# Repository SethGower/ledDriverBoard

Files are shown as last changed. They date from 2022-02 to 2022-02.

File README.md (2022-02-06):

# LED Driver Board

This is a Circuit and PCB design for an LED Strip driver I designed for personal use. I designed this to be able to have an LED strip on the perimeter of my bedroom. Given the perimeter is about 55 feet, this would require a lot of power. The original strip I looked at required 24W/m at full brightness of all 4 color channels (RGBW), since this was 60 LED/m. Due to the power requirements of this, I reduced the strip I was using to a 30 LED/m, which required 9.6 W/m. I originally designed it to drive an LED strip that doesn't have individual addressable channels. I changed the design to be able to drive an individually addressable strip, in order to have more control over the lighting.

There are three designs in this repo. The original, located in `Non_Addressable` contains the original design, which used the non addressable LED strip. The intention with this design was to use [ESPHome](https://esphome.io). The different channels were to be driven with PWM to control brightness. The Second design, for the addressable LED strips is located in `Addressable_Driver`. This was intended to be used with [WLED](https://kno.wled.ge). The final design, located in `Unified` is a combination of the two designs, on the same PCB. So only one design needs to be manufactured, and the user can decide which portion to use. All of the designs use an ESP32-DO-IT board as the controller. Make sure it is the 30 pin version.

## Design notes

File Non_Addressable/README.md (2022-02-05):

# Analog Unified LED Strip controller

This is a controller I designed to drive an RGBW 12V LED strip. Can drive up to 16A total (4A per color channel). 

This was designed with the RGBW 5050 LED Strip [here](https://ledlightsworld.com/products/dc-12v-rgbw-rgbww-high-density-30leds-9-6w-per-meter-4in1-smd5050-rgbw-led-flexible-strip-light) in mind. The intent was to surround the perimeter of my bedroom with these, which would have required around 3.5 rolls (17.5 meters). This would have required a lot of power (~160W) hence the large traces. However, pivoting to using addressable LEDs instead. But decided to keep this design for posterity's sake.

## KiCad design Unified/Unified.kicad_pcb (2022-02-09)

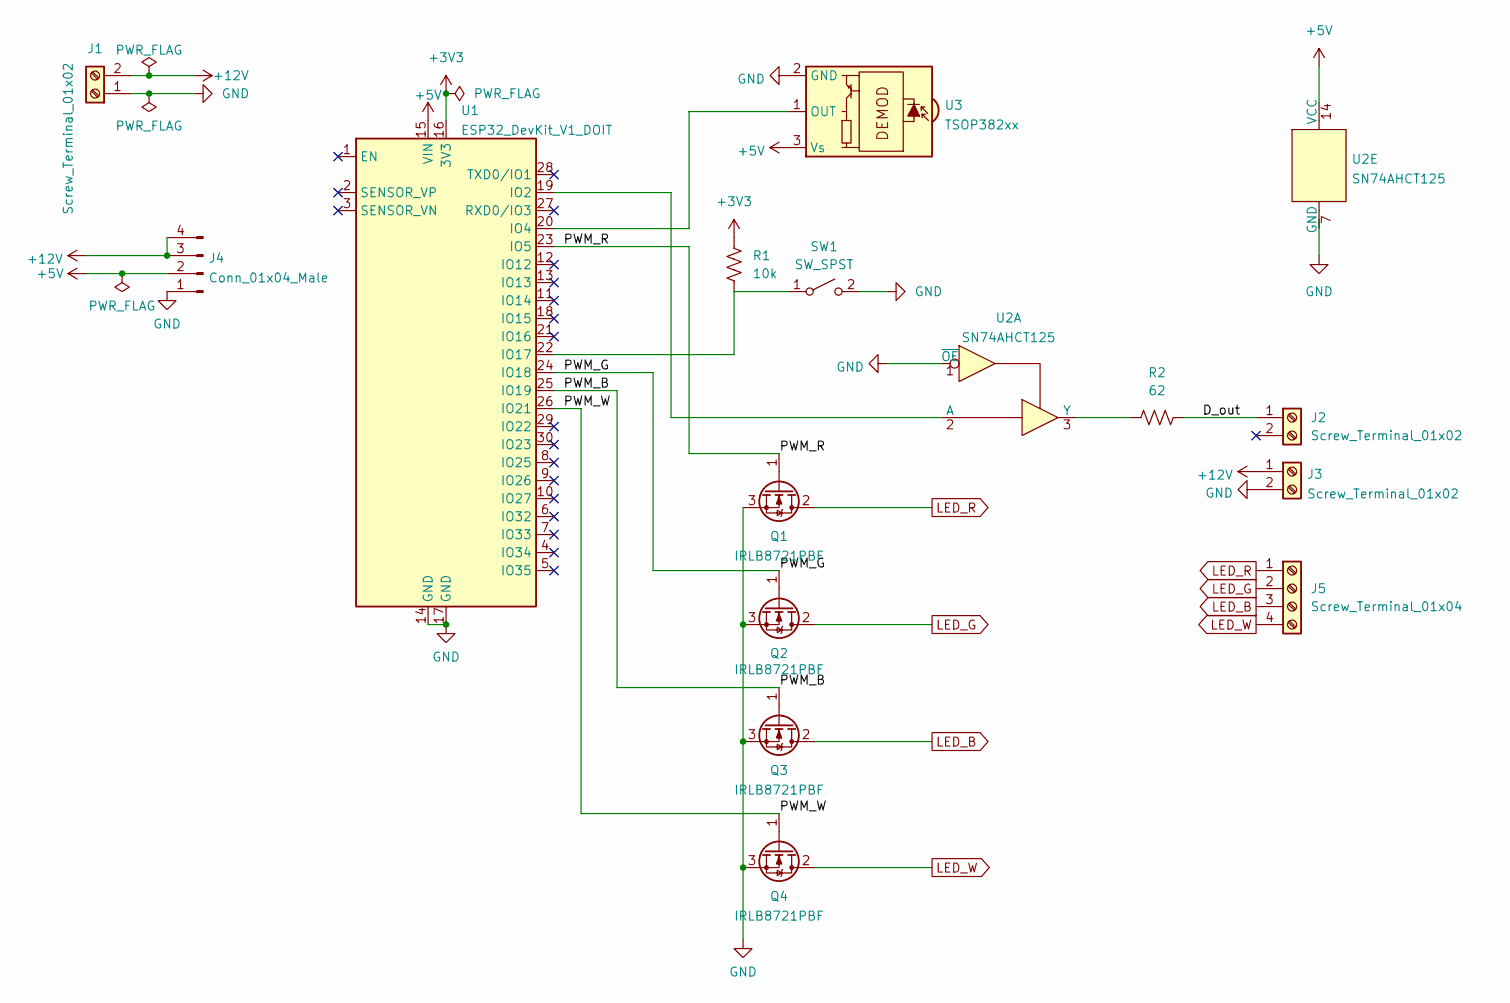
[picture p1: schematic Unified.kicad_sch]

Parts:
J1, J3: Screw_Terminal_01x02; TerminalBlock_Dinkle_DT-55-B01X-02_P10.00mm
J2: Screw_Terminal_01x02; TerminalBlock_bornier-2_P5.08mm
J4: Conn_01x04_Male; PinHeader_1x04_P2.54mm_Vertical
J5: Screw_Terminal_01x04; TerminalBlock_bornier-4_P5.08mm
Q1, Q2, Q3, Q4: IRLB8721PBF; TO-220-3_Vertical
R1: 10k; R_Axial_DIN0207_L6.3mm_D2.5mm_P7.62mm_Horizontal
R2: 62; R_Axial_DIN0207_L6.3mm_D2.5mm_P7.62mm_Horizontal
SW1: SW_SPST; SW_PUSH_6mm_H5mm
U1: ESP32_DevKit_V1_DOIT; esp32_devkit_v1_doit
U2: SN74AHCT125; DIP-14_W7.62mm
U3: TSOP382xx; Vishay_MINICAST-3Pin

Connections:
+3V3: R1.1, U1.16 (3V3)
+5V: J4.2, U1.15 (VIN), U2.14 (VCC), U3.3 (Vs)
+12V: J1.2, J3.1, J4.3, J4.4; also elsewhere on the board
/D_out: J2.1, R2.2
/PWM_B: Q3.1 (G), U1.25 (IO19)
/PWM_G: Q2.1 (G), U1.24 (IO18)
/PWM_R: Q1.1 (G), U1.23 (IO5)
/PWM_W: Q4.1 (G), U1.26 (IO21)
GND: J1.1, J3.2, J4.1, Q1.3 (S), Q2.3 (S), Q3.3 (S), Q4.3 (S), SW1.2 (B), U1.14 (GND), U1.17 (GND), U2.1 (~OE), U3.2 (GND); also elsewhere on the board
LED_B: J5.3, Q3.2 (D)
LED_G: J5.2, Q2.2 (D)
LED_R: J5.1, Q1.2 (D)
LED_W: J5.4, Q4.2 (D)
unnamed: R1.2, SW1.1 (A), U1.22 (IO17)
unnamed: R2.1, U2.3 (Y)
unnamed: U1.19 (IO2), U2.2 (A)
unnamed: U1.20 (IO4), U3.1 (OUT)

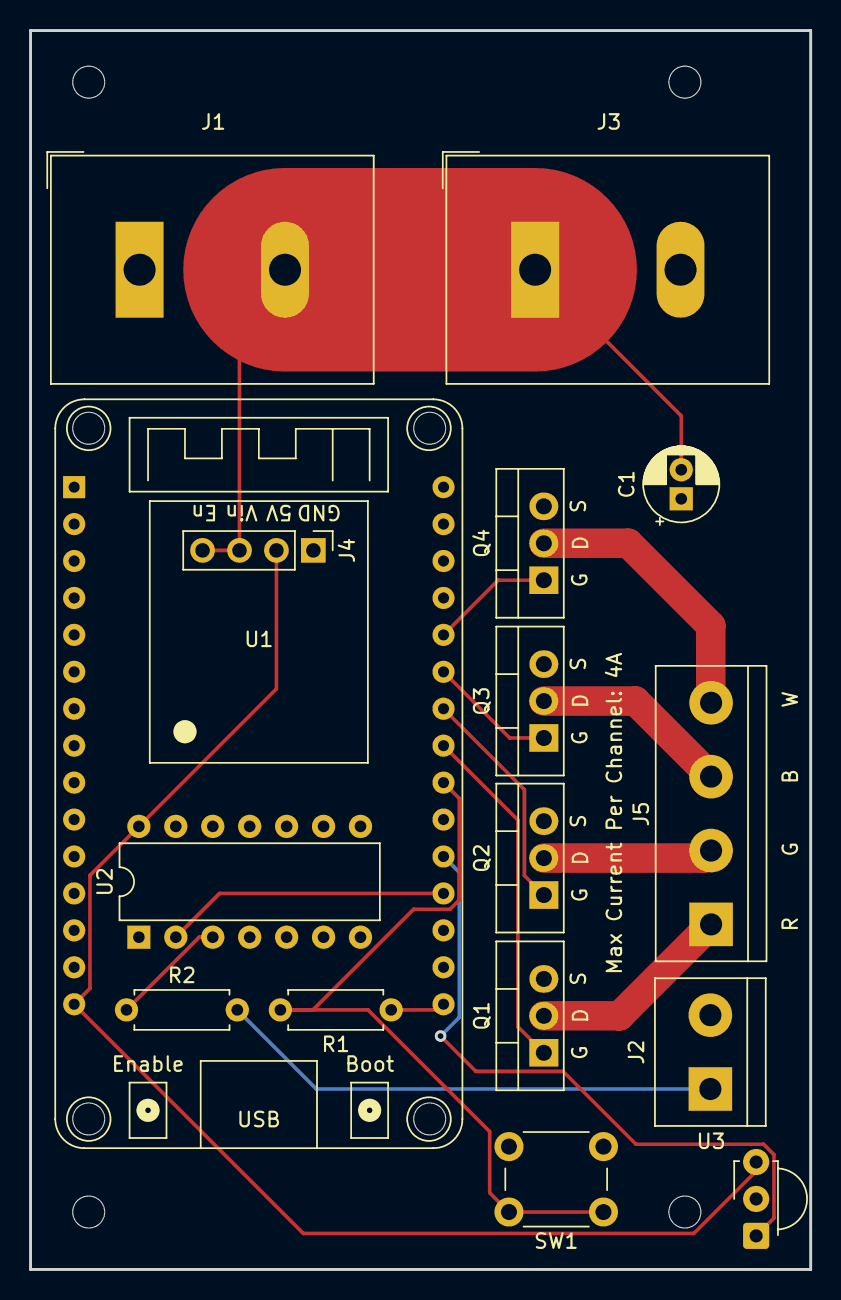
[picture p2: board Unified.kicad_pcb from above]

Board: 2 copper layers, 53.6 x 85.2 mm, 16 parts (0 on the bottom side), 17 nets.

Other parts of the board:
C1: 1000uF; CP_Radial_D5.0mm_P2.00mm

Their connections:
+12V: C1.2; also elsewhere on the board
GND: C1.1; also elsewhere on the board

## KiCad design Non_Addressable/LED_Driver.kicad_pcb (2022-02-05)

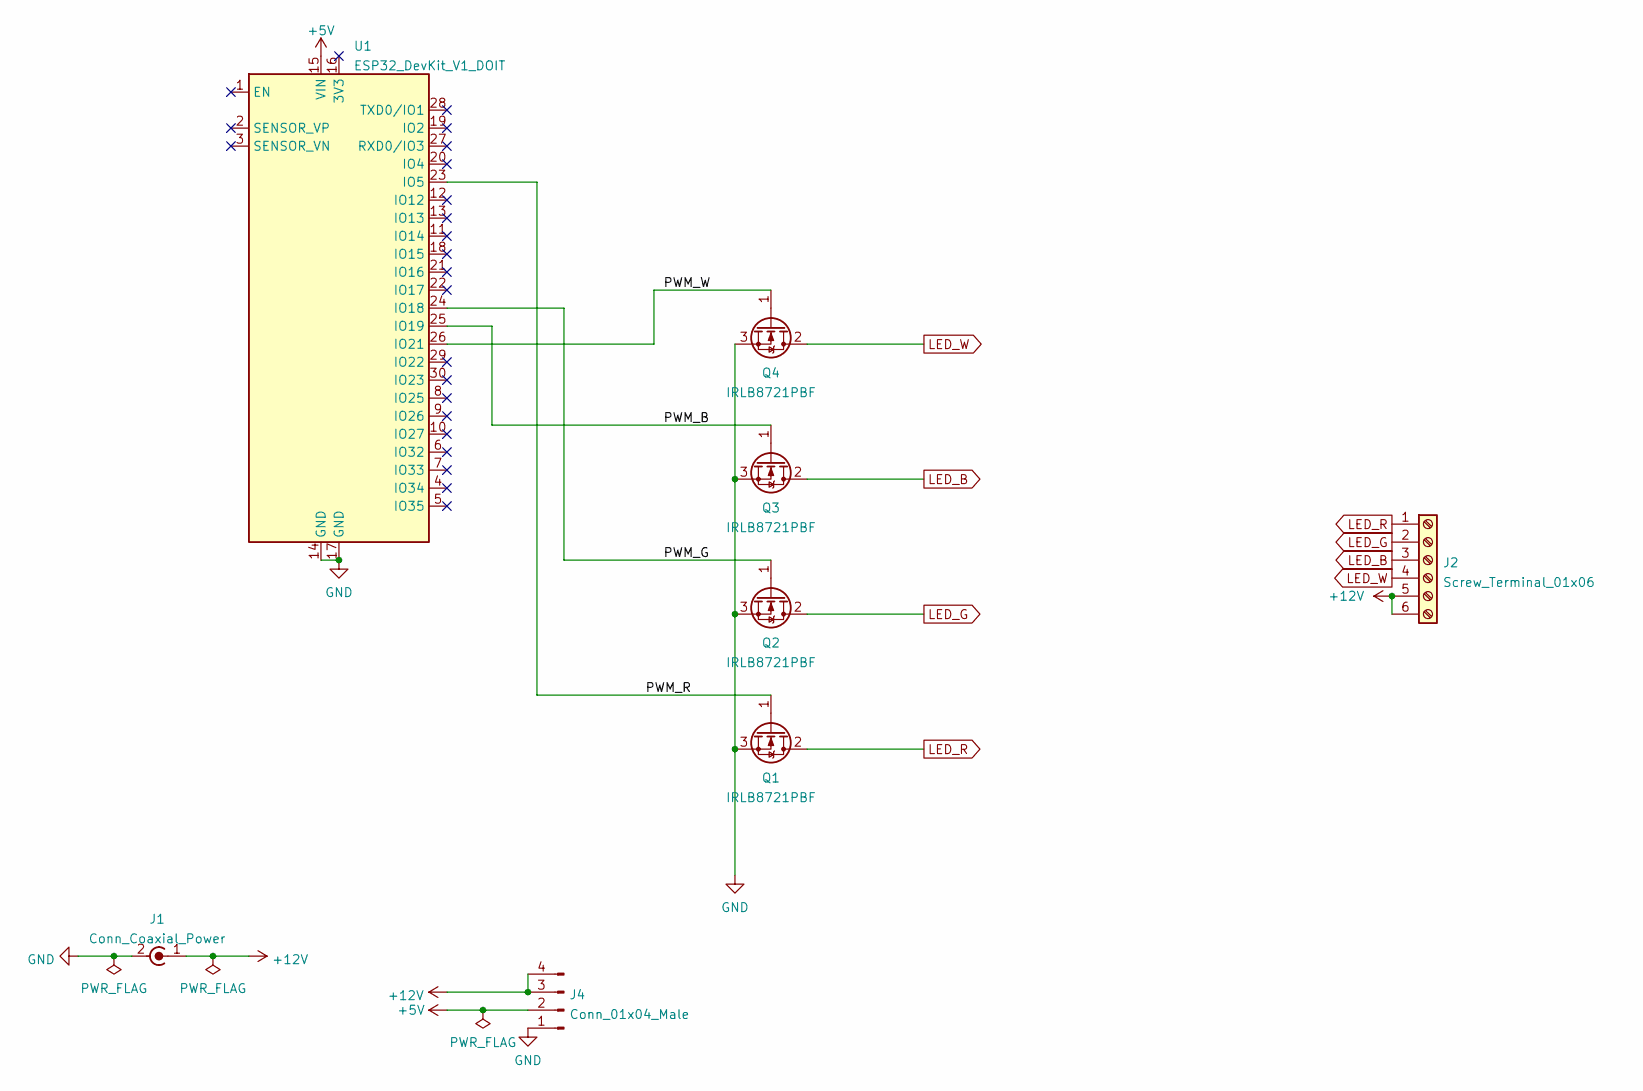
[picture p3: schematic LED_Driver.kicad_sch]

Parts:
J1: Conn_Coaxial_Power; BarrelJack_Horizontal
J2: Screw_Terminal_01x06; TerminalBlock_bornier-6_P5.08mm
J4: Conn_01x04_Male; PinHeader_1x04_P2.54mm_Vertical
Q1, Q2, Q3, Q4: IRLB8721PBF; TO-220-3_Vertical
U1: ESP32_DevKit_V1_DOIT; esp32_devkit_v1_doit

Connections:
+5V: J4.2, U1.15 (VIN)
+12V: J1.1 (In), J2.5, J2.6, J4.3, J4.4
/PWM_B: Q3.1 (G), U1.25 (IO19)
/PWM_G: Q2.1 (G), U1.24 (IO18)
/PWM_R: Q1.1 (G), U1.23 (IO5)
/PWM_W: Q4.1 (G), U1.26 (IO21)
GND: J1.2 (Ext), J4.1, Q1.3 (S), Q2.3 (S), Q3.3 (S), Q4.3 (S), U1.14 (GND), U1.17 (GND)
LED_B: J2.3, Q3.2 (D)
LED_G: J2.2, Q2.2 (D)
LED_R: J2.1, Q1.2 (D)
LED_W: J2.4, Q4.2 (D)

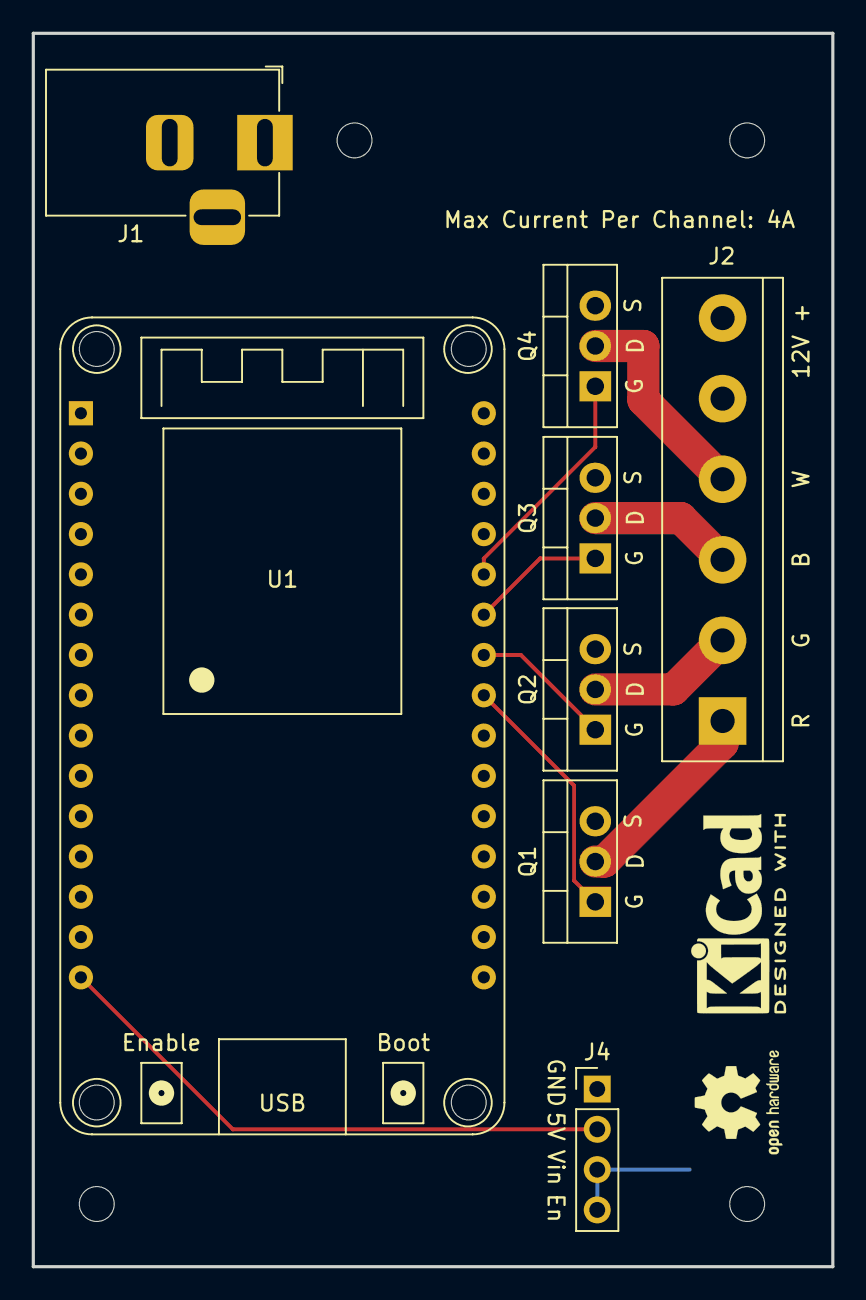
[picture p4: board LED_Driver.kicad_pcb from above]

Board: 2 copper layers, 50.4 x 77.8 mm, 8 parts (0 on the bottom side), 11 nets.

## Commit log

2022-02-01 v0.1: Initial Commit
    [LED_Driver.kicad_pcb, LED_Driver.kicad_sch]
2022-02-02 Moves PCB files into subdirectory
    [LED_Driver.kicad_pcb, LED_Driver.kicad_sch]
2022-02-03 minor updates
    [LED_Driver.kicad_pcb]
2022-02-03 Updates the connections to the ESP32. The original pins were input only pins, according to esphome
    [LED_Driver.kicad_pcb, LED_Driver.kicad_sch]
2022-02-05 Makes board smaller using proper terminal blocks
    [LED_Driver.kicad_pcb, LED_Driver.kicad_sch]
2022-02-05 Updates pins that are driving gates of transistors. 3 of the original ones were strapping pins on the esp32
    [LED_Driver.kicad_pcb, LED_Driver.kicad_sch]
2022-02-05 Moves the original design to different directory. Working on addressable version
    [LED_Driver.kicad_pcb, LED_Driver.kicad_sch]
2022-02-05 Adds design for addressable driver board
    [Addressable_Driver.kicad_pcb, Addressable_Driver.kicad_sch]
2022-02-06 Adds resistor for data output for addressable version
    [Addressable_Driver.kicad_pcb, Addressable_Driver.kicad_sch]
2022-02-06 Finishes addressable driver
    [Addressable_Driver.kicad_pcb, Addressable_Driver.kicad_sch]
2022-02-06 Moves original design
    [LED_Driver.kicad_pcb, LED_Driver.kicad_sch]
2022-02-06 Adds Unified Design. With both addressable and non addressable
    [Unified.kicad_pcb, Unified.kicad_sch]
2022-02-07 Adds ESP32 footprint stuff as a local library, instead of global
2022-02-07 Removes 12V and Ground outputs to LED strip. This will be done with thicker wire outside of PCB, due to high trace width requirements
    [Unified.kicad_pcb, Unified.kicad_sch]
2022-02-09 Adds custom symbol for the level shifter
    [Unified.kicad_pcb, Unified.kicad_sch]
